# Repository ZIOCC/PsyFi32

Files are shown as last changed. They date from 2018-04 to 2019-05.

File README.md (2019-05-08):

# Zuino XS PsyFi32 (ESP32, Qwiic, 3.3V, WIFI, BLE)

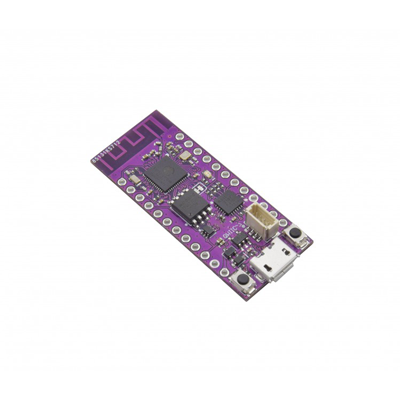
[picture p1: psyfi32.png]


> This product can be available for purchase [here](https://www.smart-prototyping.com/Zuino-XS-PsyFi32.html).

#### Description

The PsyFi32 squeezes an ESP32 development platform into a board with the pinout of Sparkfun’s Pro Micro, and with a footprint that is only a teensy bit longer, is light as a feather and that we hope will be as commonly found on any workbench as oranges are in any grove.

Actually, one might say it looks suspiciously like an ESP32 Thing with slightly fewer pins (don’t worry, we picked them carefully) and without a battery charger. That’s because one of our employees came to us and said “I want an ESP32 Thing with a Pro Micro’s footprint, and with a Qwiic connector on it.” So here it is.

For your battery charging, monitoring, and regulating needs, we’ve created the ZIO LiPo Battery Manager, which can power the PsyFi32 and plenty of additional sensor and actuator modules over the Qwiic bus.

While you can certainly program this board with the Espressif native toolchain, we’ve made this board specifically for you Arduino fans out there, which is why we picked the form-factor of one of the most beloved and widely-used Arduino-compatible boards. 

And while you might not know it from the Sparkfun ESP32 Thing product page, the ESP32 Arduino Core is pretty full-featured at this point, including support for BLE and acting as a web server. (Let us know when you’ve updated your page, guys, so we can update ours. ;) )

To use with the Arduino IDE, install [Espressif's ESP32 Arduino core](https://github.com/espressif/arduino-esp32).

For our Mocap suit demo, we used Wire library files transplanted from [Stickbreaker's ESP32 Arduino Core fork](https://github.com/stickbreaker/arduino-esp32/tree/Wire-Destructor#development-status). 

In case you’re wondering about the name: it’s a trifecta of fun references.

> Note: As with all of the Version 1.0 Zio Qwiic boards, this board has been produced with the I2C pull-ups disconnected by default. If there's a significant length of wire between this board and your MCU, you'll need to solder closed the solder jumpers (labeled SDA, 3v3 and SCL) to connect the pull-up resistors to VCC.

##### PsyFi32 Dev Board PINMAP

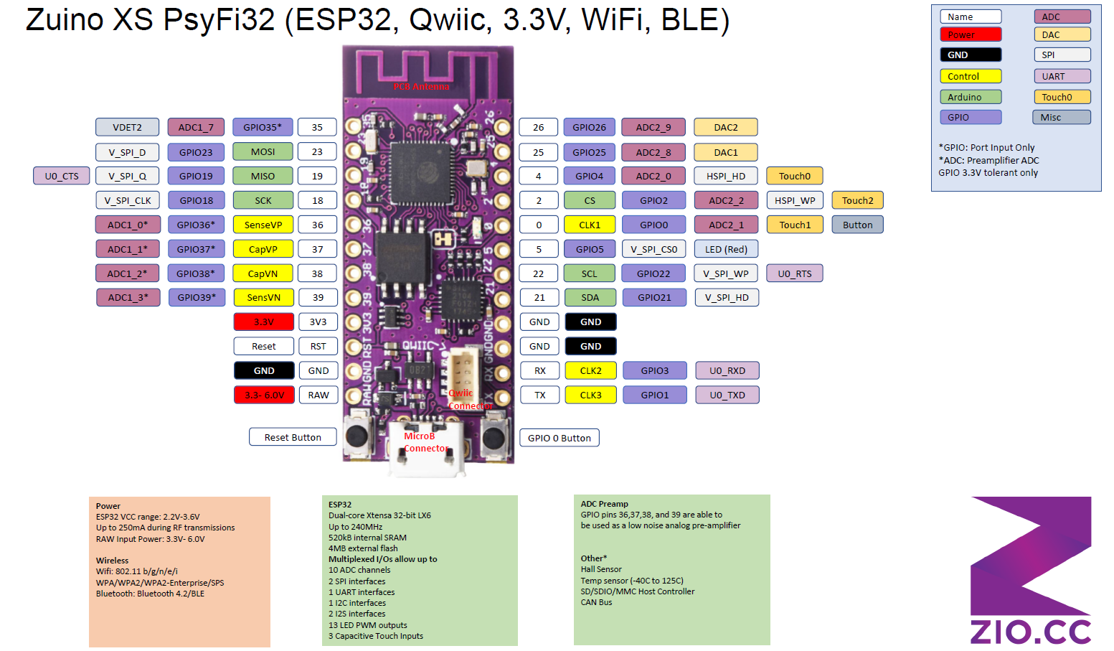
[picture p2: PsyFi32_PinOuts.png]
Pin Functions


#### Specification

* ESP32-D0WDQ6
* Weight 2.4g (0.084oz

#### Links

* [esp32_datasheet](https://www.smart-prototyping.com/image/data/NOA-RnD/101887%20Psyfi/esp32_datasheet_en.pdf)
* [Arduino core for the ESP32](https://github.com/espressif/arduino-esp32)
* [Eagle Files](https://github.com/ZIOCC/PsyFi32)
* [Very Detailed Introduction for ESP32 on Instructables.com](https://www.instructables.com/id/IOT-Made-Simple-Playing-With-the-ESP32-on-Arduino-/)

> ###### About Zio
> Zio is a new line of open sourced, compact, and grid layout boards, fully integrated for Arduino and Qwiic ecosystem. Designed ideally for wearables, robotics, small-space limitations or other on the go projects. Check out other awesome Zio products [here](https://www.smart-prototyping.com/Zio).

> All Zio products are released under the [Creative Commons Attribution, Share-Alike License](https://creativecommons.org/licenses/by-sa/4.0/), and in accordance with the principles of the [Open Source Hardware Association's OSHW Statement of Principles 1.0 and OSHW Definition 1.0](https://www.oshwa.org/definition/).

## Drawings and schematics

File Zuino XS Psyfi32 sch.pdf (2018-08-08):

GND | GND 26MHz | XC⁶²¹⁰B³³²MRU²
SUSPEND | 17 CTS | 18 RTS | 19 RXD | 20 TXD | 21 DSR | 22 DTR | 23 DCD | 24 GND_PAD | 25

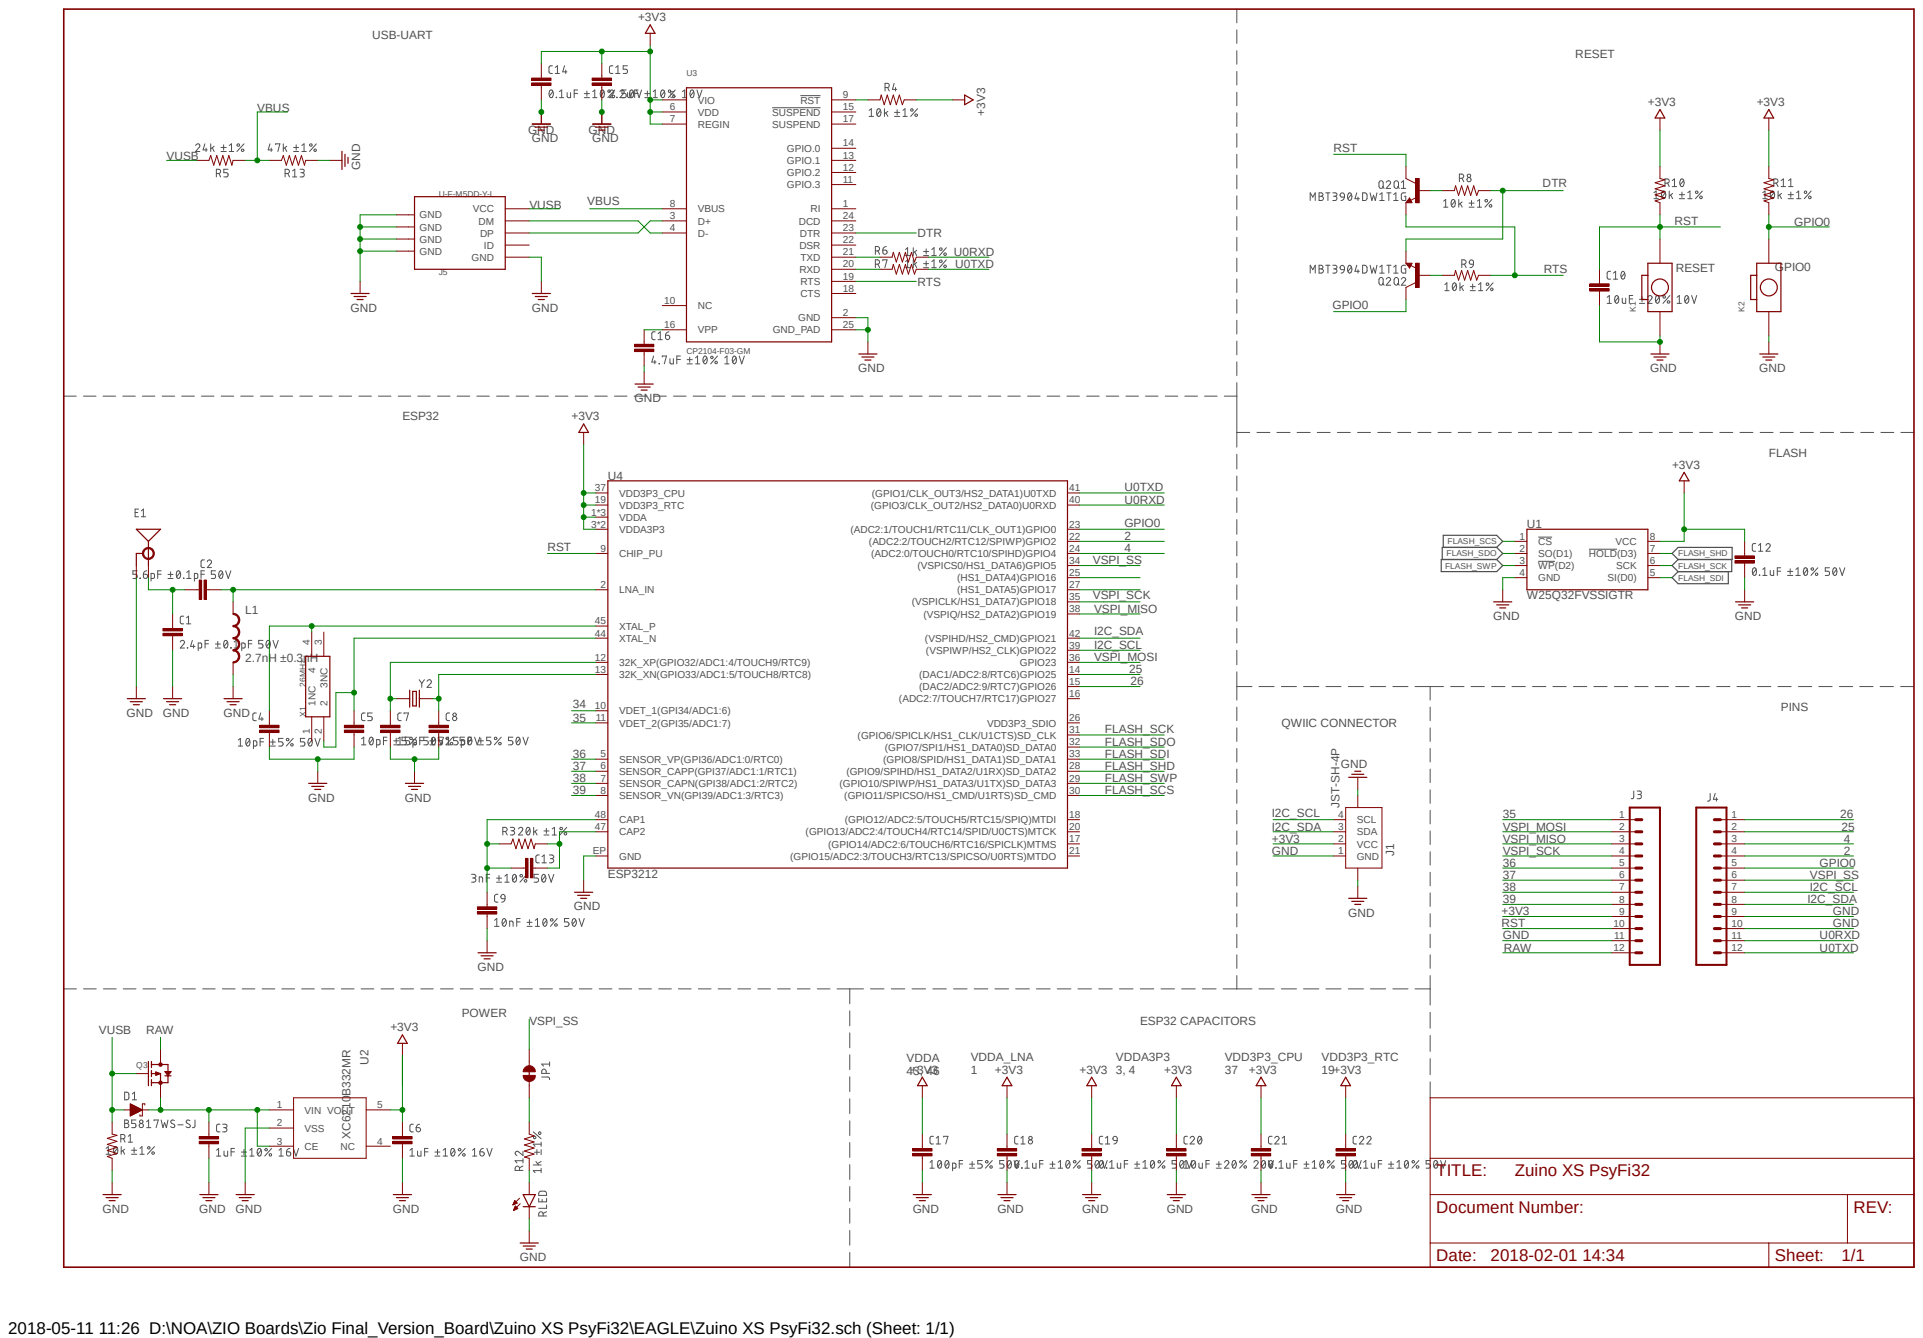
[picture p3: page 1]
RESET; GPIO0; VDDA 43, 46; VDDA_LNA 1; VDDA3P3 3, 4; VDD3P3_CPU 37; VDD3P3_RTC 19; ESP32; FLASH; PINS; USB-UART; POWER; ESP32 CAPACITORS; QWIIC CONNECTOR; RESET CP2104-F03-GM; ESP3212; W25Q32FVSSIGTR; GND; GND GND; 1 GND; VIO 5; VDD 6; REGIN 7; VBUS 8; RST; GPIO.3; 11 GPIO.2; 12 GPIO.1; 13 GPIO.0; 14 SUSPEND; 15 VPP 16; SENSOR_CAPP(GPI37/ADC1:1/RTC1) 6; SENSOR_VP(GPI36/ADC1:0/RTC0) 5; VDDA3P3 3*2; LNA_IN 2; SENSOR_CAPN(GPI38/ADC1:2/RTC2) 7; SENSOR_VN(GPI39/ADC1:3/RTC3) 8; CHIP_PU 9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

VCC GND GND GND GND

4 VIN 1 VSS 2 CE 3 NC 4 VOUT 5 Q3 K1K2

Document Number: | REV:

Date: 2018-02-01 14:34 | Sheet: 1/1

2018-05-11 11:26 D:\NOA\ZIO Boards\Zio Final_Version_Board\Zuino XS PsyFi32\EAGLE\Zuino XS PsyFi32.sch (Sheet: 1/1)

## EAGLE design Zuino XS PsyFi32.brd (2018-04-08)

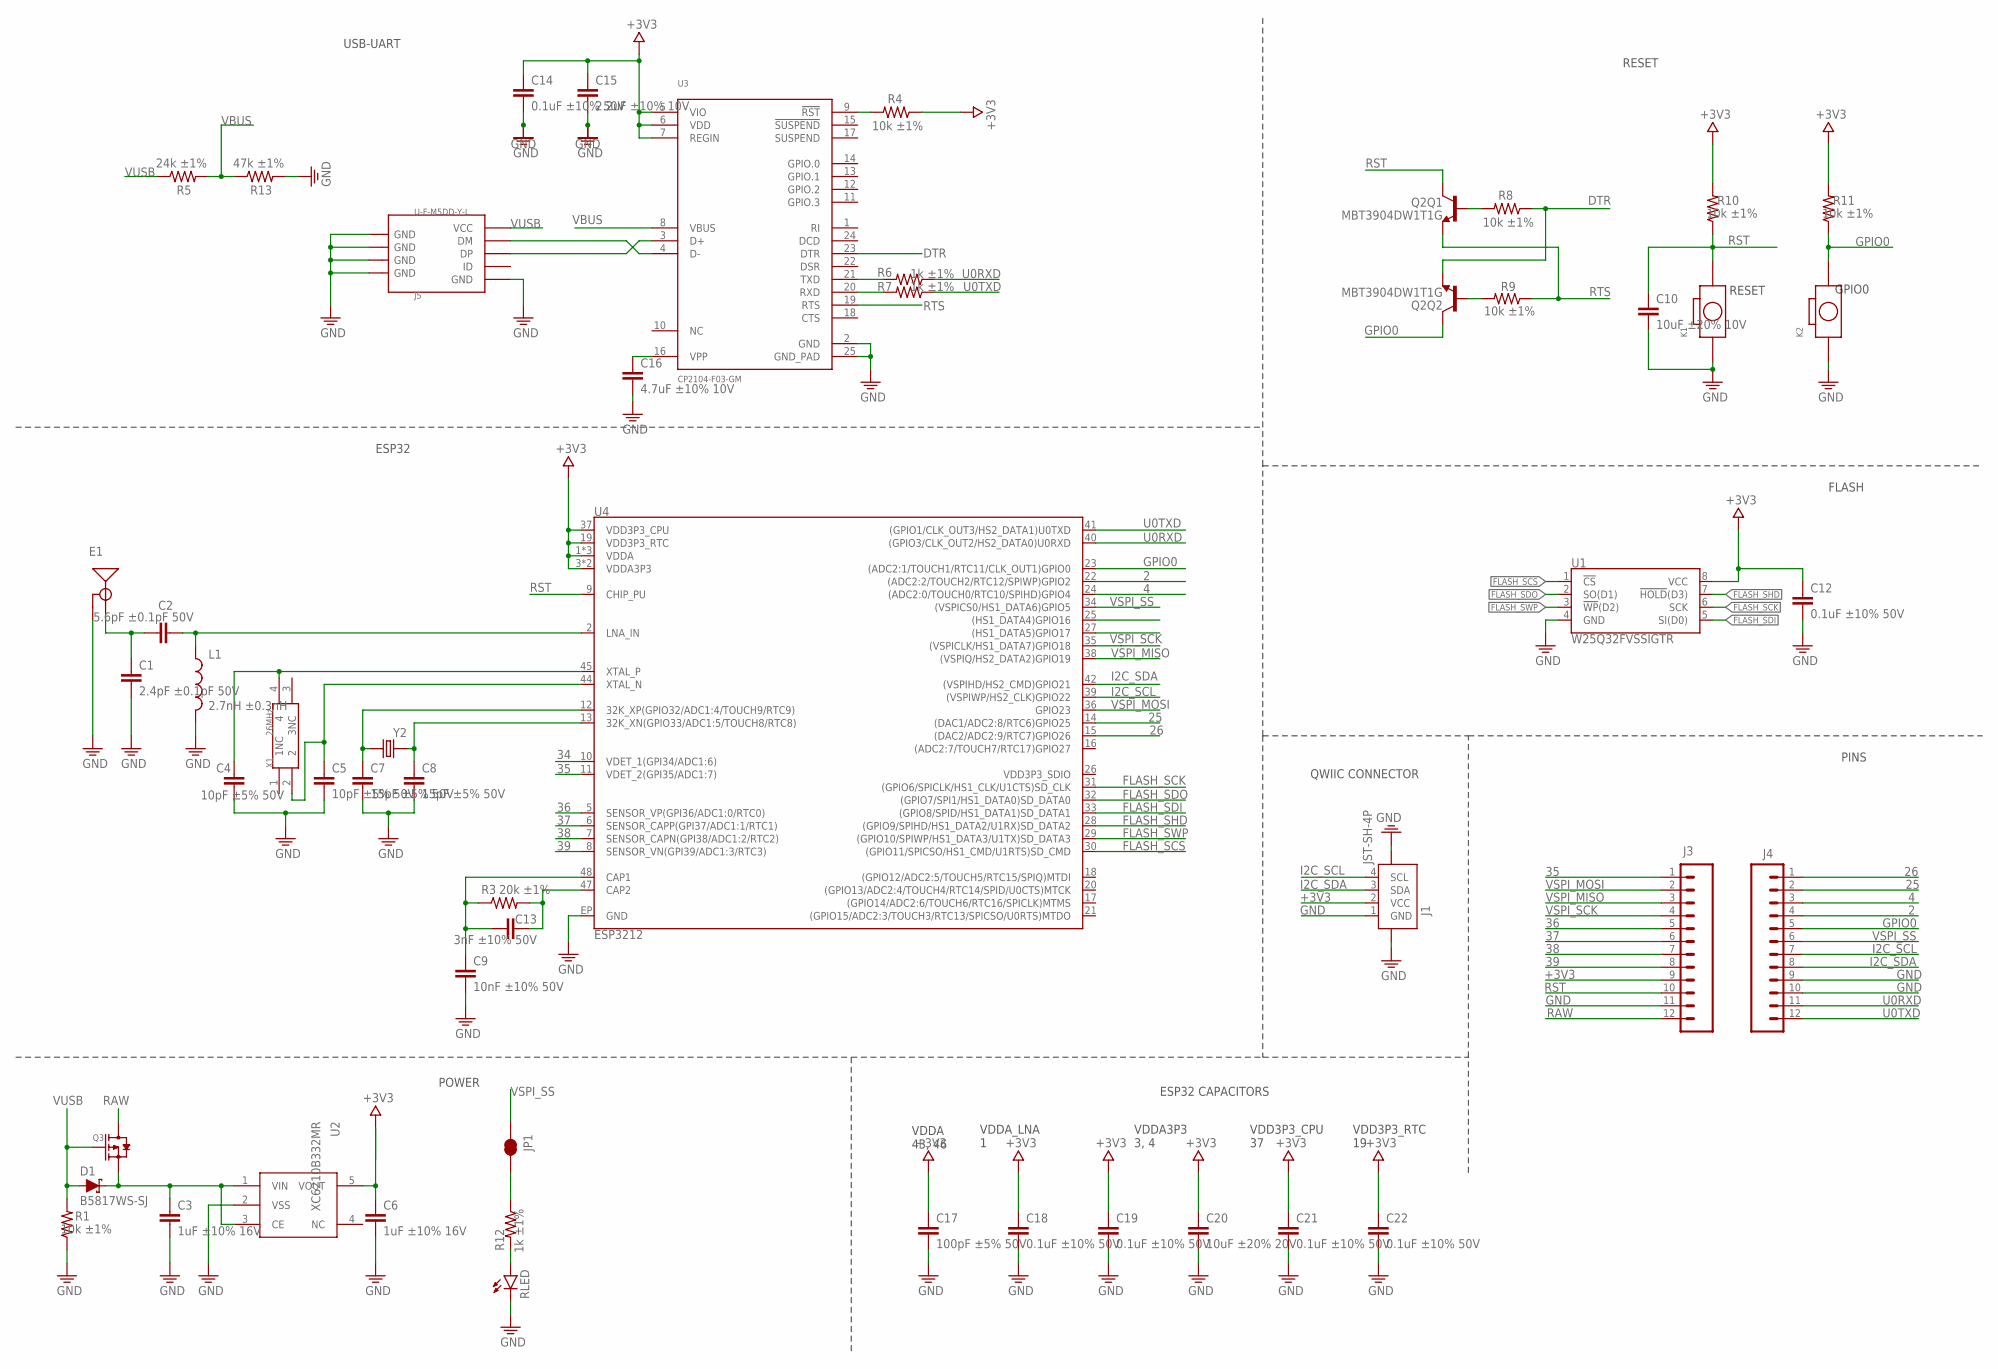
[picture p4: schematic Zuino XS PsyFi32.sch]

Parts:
C1: 2.4pF ±0.1pF 50V; YAGEO_C_0402
C2: 5.6pF ±0.1pF 50V; YAGEO_C_0402
C3, C6: 1uF ±10% 16V; YAGEO_C_0402
C4, C5: 10pF ±5% 50V; YAGEO_C_0402
C7, C8: 15pF ±5% 50V; YAGEO_C_0402
C9: 10nF ±10% 50V; YAGEO_C_0402
C10: 10uF ±20% 10V; YAGEO_C_0402
C12, C14, C18, C19, C21, C22: 0.1uF ±10% 50V; YAGEO_C_0402
C13: 3nF ±10% 50V; YAGEO_C_0402
C15: 2.2uF ±10% 10V; YAGEO_C_0402
C16: 4.7uF ±10% 10V; YAGEO_C_0402
C17: 100pF ±5% 50V; YAGEO_C_0402
C20: 10uF ±20% 20V; YAGEO_C_0402
D1: B5817WS-SJ; SOD-323
D2: RLED; LED_HSMH-C190
E1: ANTENNA-GROUNDED; ANTENNA_ESP32
J1: JST-SH-4P; JST-SH-4P-90
J3, J4: CONN_12; 1X12
J5: U-F-M5DD-Y-L; MICRO-SMD
JP1: JUMPER-SMT_2_NC_TRACE_SILK; SMT-JUMPER_2_NC_TRACE_SILK
K1, K2: BOTTON-2PSKRKAEE020; SKRKAEE020
L1: 2.7nH ±0.3nH; INDUCTOR_HK10052N7S-T
Q2: MBT3904DW1T1G; SC70-6
Q3: MOSFET-P-323; SOT-323
R1, R4, R8, R9, R10, R11: 10k ±1%; YAGEO_R_0402
R3: 20k ±1%; YAGEO_R_0402
R5: 24k ±1%; YAGEO_R_0402
R6, R7, R12: 1k ±1%; YAGEO_R_0402
R13: 47k ±1%; YAGEO_R_0402
U1: W25Q32FVSSIGTR; SOIC-8
U2: XC6210B332MR; SOT23-5
U3: CP2104-F03-GM; QFN24-CP2104
U4: ESP3212; QFN48-0.4MM
X1: 26MHz; 4P-SMD-2X1.6MM
Y2: 32.768kHz; CRYSTAL_2012

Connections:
2: J4.4, U4.22 ((ADC2:2/TOUCH2/RTC12/SPIWP)GPIO2)
4: J4.3, U4.24 ((ADC2:0/TOUCH0/RTC10/SPIHD)GPIO4)
25: J4.2, U4.14 ((DAC1/ADC2:8/RTC6)GPIO25)
26: J4.1, U4.15 ((DAC2/ADC2:9/RTC7)GPIO26)
34: U4.10 (VDET_1(GPI34/ADC1:6))
35: J3.1, U4.11 (VDET_2(GPI35/ADC1:7))
36: J3.5, U4.5 (SENSOR_VP(GPI36/ADC1:0/RTC0))
37: J3.6, U4.6 (SENSOR_CAPP(GPI37/ADC1:1/RTC1))
38: J3.7, U4.7 (SENSOR_CAPN(GPI38/ADC1:2/RTC2))
39: J3.8, U4.8 (SENSOR_VN(GPI39/ADC1:3/RTC3))
+3V3: C6.1, C12.1, C14.1, C15.1, C17.1, C18.1, C19.1, C20.1, C21.1, C22.1, J1.2 (VCC), J3.9, R4.1, R10.2, R11.2, U1.8 (VCC), U2.5 (VOUT), U3.5 (VIO), U3.6 (VDD), U3.7 (REGIN), U4.1 (VDDA), U4.3 (VDDA3P3), U4.4 (VDDA3P3), U4.19 (VDD3P3_RTC), U4.37 (VDD3P3_CPU), U4.43 (VDDA), U4.46 (VDDA)
DTR: Q2.1 (E), R8.1, U3.23 (DTR)
FLASH_SCK: U1.6 (SCK), U4.31 ((GPIO6/SPICLK/HS1_CLK/U1CTS)SD_CLK)
FLASH_SCS: U1.1 (!CS!), U4.30 ((GPIO11/SPICSO/HS1_CMD/U1RTS)SD_CMD)
FLASH_SDI: U1.5 (SI(D0)), U4.33 ((GPIO8/SPID/HS1_DATA1)SD_DATA1)
FLASH_SDO: U1.2 (SO(D1)), U4.32 ((GPIO7/SPI1/HS1_DATA0)SD_DATA0)
FLASH_SHD: U1.7 (!HOLD!(D3)), U4.28 ((GPIO9/SPIHD/HS1_DATA2/U1RX)SD_DATA2)
FLASH_SWP: U1.3 (!WP!(D2)), U4.29 ((GPIO10/SPIWP/HS1_DATA3/U1TX)SD_DATA3)
GND: C1.2, C3.2, C4.2, C5.2, C6.2, C7.2, C8.2, C9.2, C10.2, C12.2, C14.2, C15.2, C16.2, C17.2, C18.2, C19.2, C20.2, C21.2, C22.2, D2.1 (C), E1.GND, J1.1 (GND), J1.5, J1.6, J3.11, J4.9, J4.10, J5.GND, J5.S1 (GND), J5.S1@1 (GND), J5.S1@2 (GND), J5.S2 (GND), J5.S2@1 (GND), J5.S2@2 (GND), J5.S3 (GND), J5.S3@1 (GND), J5.S3@2 (GND), J5.S4 (GND), J5.S4@1 (GND), J5.S4@2 (GND), K1.1, K2.1, L1.2, R1.1, R13.2, U1.4 (GND), U2.2 (VSS), U3.2 (GND), U3.25 (GND_PAD), U4.EP (GND)
GPIO0: J4.5, K2.2, Q2.6 (C), R11.1, U4.23 ((ADC2:1/TOUCH1/RTC11/CLK_OUT1)GPIO0)
I2C_SCL: J1.4 (SCL), J4.7, U4.39 ((VSPIWP/HS2_CLK)GPIO22)
I2C_SDA: J1.3 (SDA), J4.8, U4.42 ((VSPIHD/HS2_CMD)GPIO21)
unnamed: C7.1, U4.12 (32K_XP(GPIO32/ADC1:4/TOUCH9/RTC9)), Y2.1
unnamed: C8.1, U4.13 (32K_XN(GPIO33/ADC1:5/TOUCH8/RTC8)), Y2.2
unnamed: C9.1, C13.1, R3.1, U4.48 (CAP1)
unnamed: C4.1, U4.45 (XTAL_P), X1.4
unnamed: C5.1, U4.44 (XTAL_N), X1.2
unnamed: C13.2, R3.2, U4.47 (CAP2)
unnamed: C1.1, C2.1, E1.ANT (SIGNAL)
unnamed: C2.2, L1.1, U4.2 (LNA_IN)
unnamed: R6.2, U3.21 (TXD)
unnamed: J5.D+ (DP), U3.3 (D+)
unnamed: J5.D- (DM), U3.4 (D-)
unnamed: R4.2, U3.9 (!RST)
unnamed: R7.2, U3.20 (RXD)
unnamed: Q2.2 (B), R9.2
unnamed: Q2.5 (B), R8.2
unnamed: D2.2 (A), R12.2
unnamed: C16.1, U3.16 (VPP)
unnamed: JP1.2, R12.1
RAW: J3.12, Q3.3 (D)
RST: C10.1, J3.10, K1.2, Q2.3 (C), R10.1, U4.9 (CHIP_PU)
RTS: Q2.4 (E), R9.1, U3.19 (RTS)
U0RXD: J4.11, R6.1, U4.40 ((GPIO3/CLK_OUT2/HS2_DATA0)U0RXD)
U0TXD: J4.12, R7.1, U4.41 ((GPIO1/CLK_OUT3/HS2_DATA1)U0TXD)
VBUS: R5.2, R13.1, U3.8 (VBUS)
VIN: C3.1, D1.C, Q3.2 (S), U2.1 (VIN), U2.3 (CE)
VSPI_MISO: J3.3, U4.38 ((VSPIQ/HS2_DATA2)GPIO19)
VSPI_MOSI: J3.2, U4.36 (GPIO23)
VSPI_SCK: J3.4, U4.35 ((VSPICLK/HS1_DATA7)GPIO18)
VSPI_SS: J4.6, JP1.1, U4.34 ((VSPICS0/HS1_DATA6)GPIO5)
VUSB: D1.A, J5.VBUS (VCC), Q3.1 (G), R1.2, R5.1

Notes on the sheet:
RESET
GPIO0
VDDA 43, 46
VDDA_LNA 1
VDDA3P3 3, 4
VDD3P3_CPU 37
VDD3P3_RTC 19
ESP32
FLASH
PINS
USB-UART
POWER
ESP32 CAPACITORS
QWIIC CONNECTOR

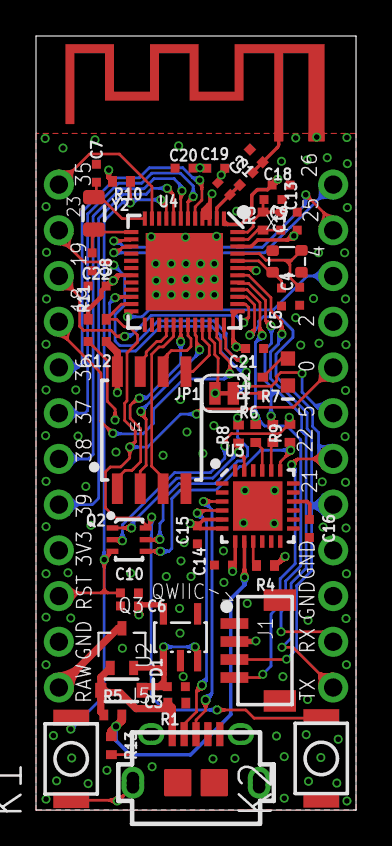
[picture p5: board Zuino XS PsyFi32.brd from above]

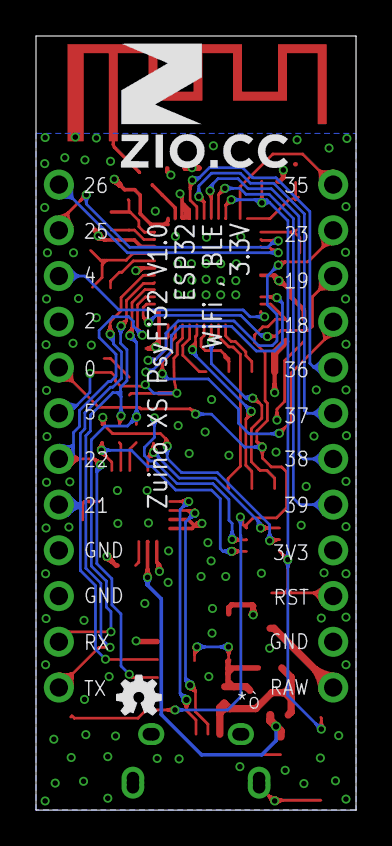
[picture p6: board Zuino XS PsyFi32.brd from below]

Board: 4 copper layers, 17.8 x 43.0 mm, 54 parts (2 on the bottom side), 51 nets.

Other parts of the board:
U$1: SPARKFUN-AESTHETICS_OSHW-LOGO-MINI
U$18: 7MM

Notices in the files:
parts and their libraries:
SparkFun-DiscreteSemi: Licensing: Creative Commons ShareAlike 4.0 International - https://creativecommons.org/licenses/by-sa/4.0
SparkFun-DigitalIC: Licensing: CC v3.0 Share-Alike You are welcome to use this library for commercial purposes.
